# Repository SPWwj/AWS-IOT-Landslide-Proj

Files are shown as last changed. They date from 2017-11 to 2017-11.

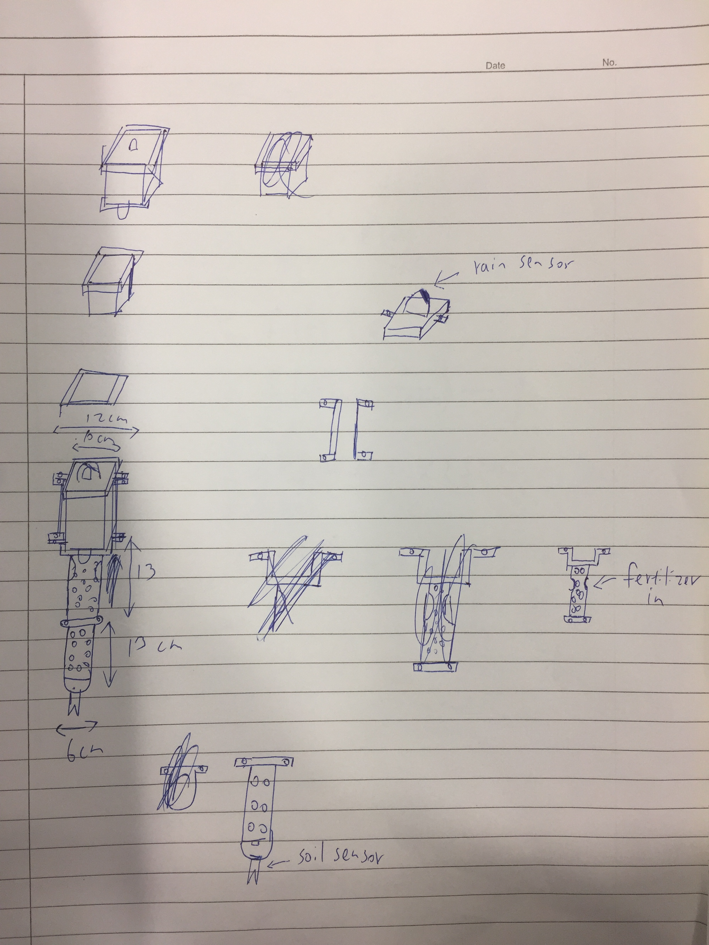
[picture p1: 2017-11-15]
3DDesign/3dSketch.JPG

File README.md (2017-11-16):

**1. Introduction**

SPMakers is a team of two year two students taking Diploma in Computer Engineering in Singapore Polytechnic. We are inspired to build an end-to-end IoT cloud computing system to make the world a better and safer place to live. The MakeSense1 is our solution, utilizing our self-developed IoT enabled microcontroller known as the &quot;SPEEEduino&quot; and Amazon Web Service&#39;s various cloud computing services to collect, store and perform computations on data, and finally provides visualization over the Internet using the D3 library.

**2. Problems and Research**

Landslides form silently, with minimal signs, and is considered one of the most difficult natural disasters to predict. Landslides are highly localized, and warnings often come too late for the people living there to take any life-saving action.

**3. Our Solution**

The MakeSense1 aims to acquire environmental parameters relevant to landslides while doubling as a conservation tool, as its hollow tubes with Voronoi patterns allows for one to deposit fertilizer in the tubes, feeding nearby vegetation which proactively prevents landslides. The MakeSense1 also aims to feeds data into a third-party machine learning based landslide prediction platform.

**3.1 System Diagram and Operation**


The MakeSense1 mainly consists of 3 subsystems: (i) Sensing Subsystem; (ii) Cloud Computing Subsystem; and (iii) Visualization Subsystem. The Sensing Subsystem uses the SPEEEduino, an IoT enabled microcontroller, and interfaces with 3 sensors: an IMU (Inertial Measurement Unit), a rainfall sensor, and a soil moisture sensor, contained in a 3D-printed enclosure with an IP65 waterproof box. The SPEEEduino has an ESP8266-01 Wi-Fi module onboard, allowing it to communicate to the Internet via gateways. It is modular and adaptable to technologies like SigFox and LoRa. The Cloud Computing Subsystem uses Amazon&#39;s AWS IoT, SNS and DynamoDB services to capture, store and process data sensed. The Visualization subsystem is a web interface that displays all the data from the database using the D3 library.

MakeSense1 Node


**3.3 Future plans**

Future development plans include (i) mesh networking between individual MakeSense1 nodes, allowing coverage of the entire area with wireless networking and (ii) feeding sensor data into a machine learning platform for early detection of environmental disasters.

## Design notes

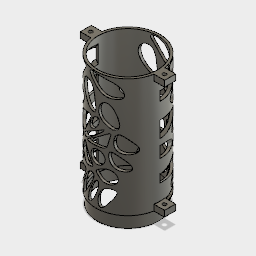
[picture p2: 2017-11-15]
3DDesign/BTMMID/MIDDLEv2 v0XXX.png

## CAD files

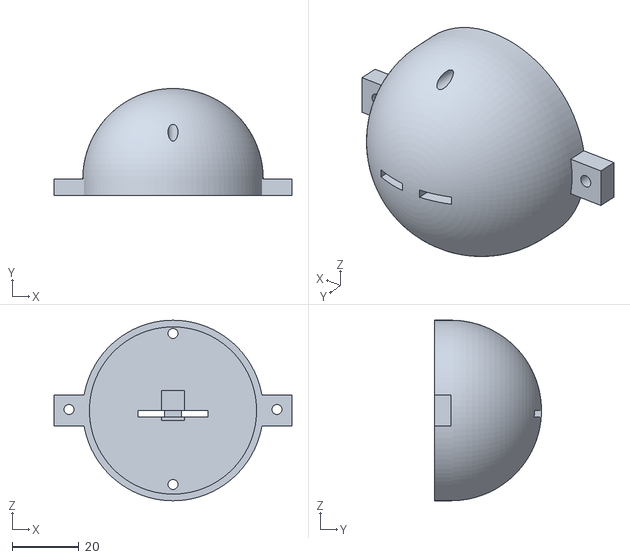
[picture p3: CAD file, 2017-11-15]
3DDesign/BTMBTM/Body5.stl
71.2 x 32.0 x 54.0

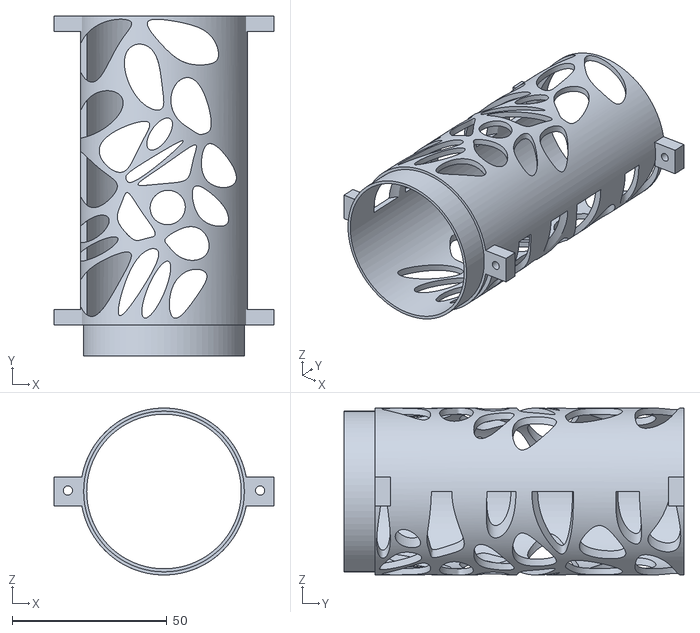
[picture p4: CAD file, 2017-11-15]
3DDesign/BTMMID/Body2.stl
71.2 x 110.0 x 54.0

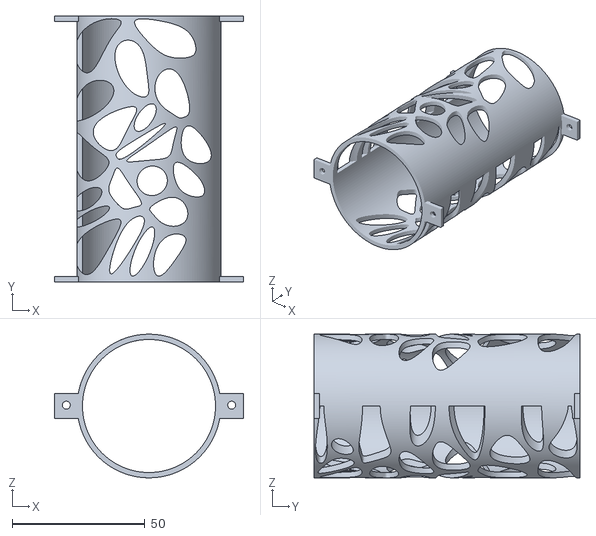
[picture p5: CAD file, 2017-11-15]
3DDesign/BTMMIDRe/Body2.stl
71.2 x 100.0 x 54.0

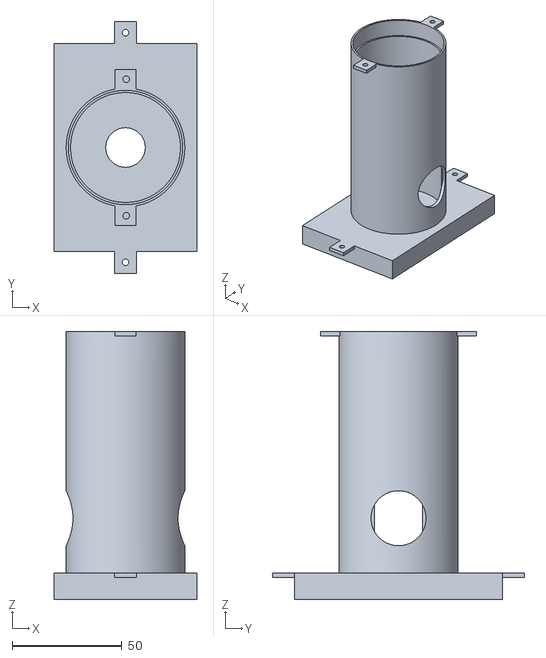
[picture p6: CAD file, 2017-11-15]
3DDesign/BTMTOP/BTMTOPHolderREDOSLT.stl
65.0 x 114.5 x 122.0

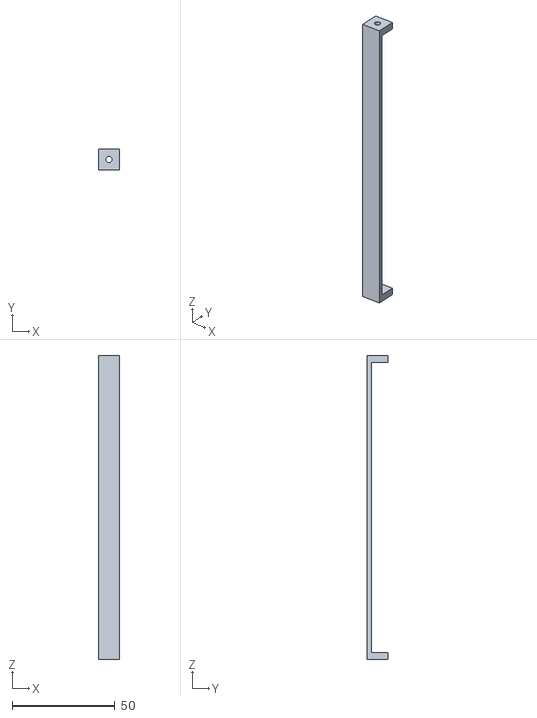
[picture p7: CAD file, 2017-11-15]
3DDesign/Connector/connector148.stl
10.0 x 10.0 x 148.0

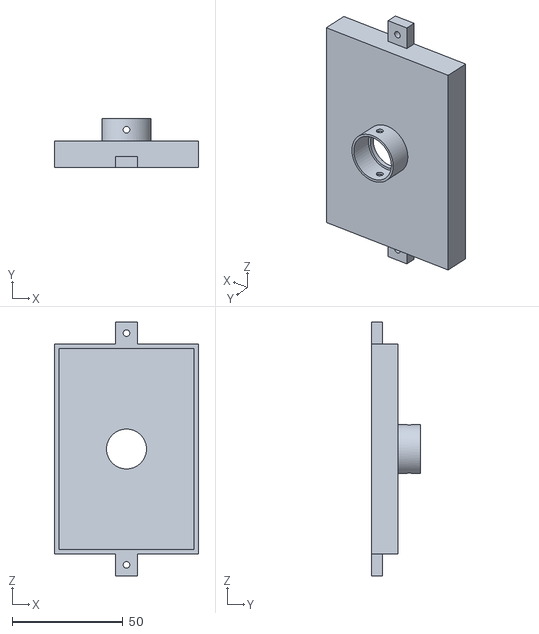
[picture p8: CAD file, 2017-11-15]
3DDesign/TOP/TOPBody1.stl
65.0 x 22.0 x 114.5

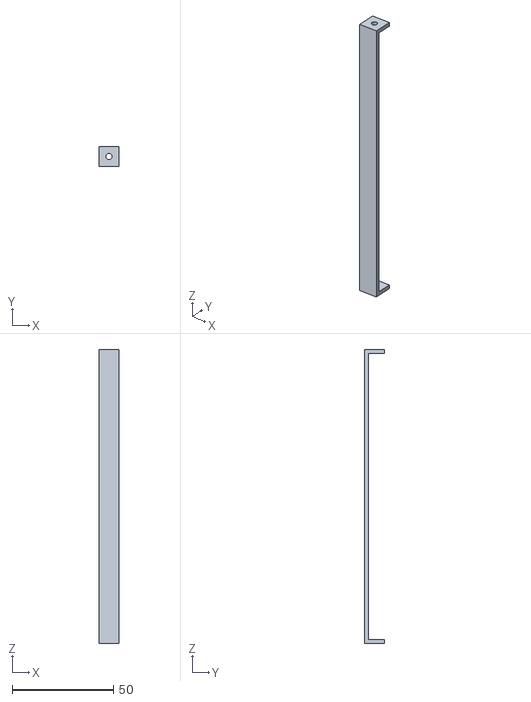
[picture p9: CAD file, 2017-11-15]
3DDesign/Connector/TOPBody1.stl
10.0 x 10.0 x 145.0

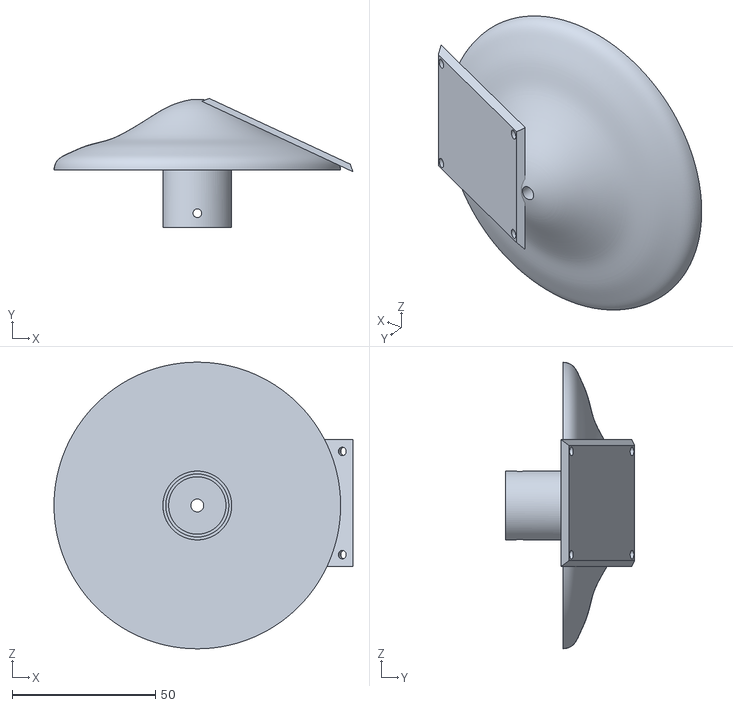
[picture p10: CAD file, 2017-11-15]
3DDesign/TOP/MS.stl
104.3 x 45.1 x 100.0

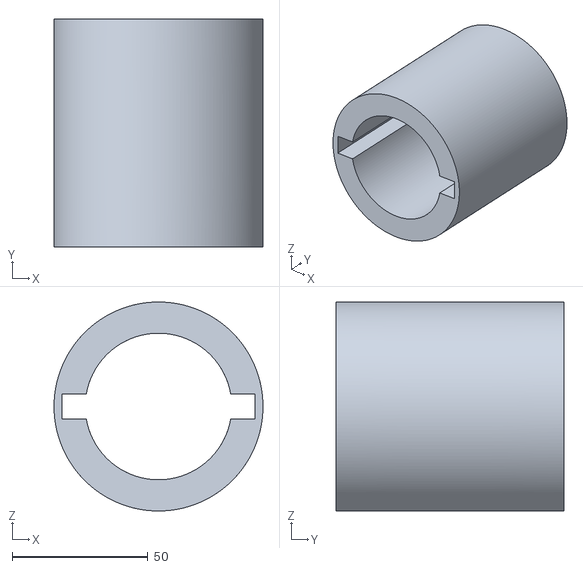
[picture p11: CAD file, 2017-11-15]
3DDesign/Connector/Body15SUPPORT.stl
77.0 x 84.0 x 77.0

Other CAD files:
3DDesign/BTMBTM/btmbtm - Copy.f3d
3DDesign/BTMBTM/btmbtm.f3d
3DDesign/BTMMID/MIDDLEv2 v0XXX.f3d
3DDesign/Connector/Untitled v1.f3d
3DDesign/TOP/modiTOP v4.f3d

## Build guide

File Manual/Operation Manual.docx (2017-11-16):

AWS IoT App Challenge Operation Manual

Title: MakeSense1

Country: Singapore

University/Institute:

Singapore Polytechnic

Members: Pan Ziyue

Wei Wen Jie

Mentor: Teo Shin Jen

# Foreword and Overview

MakeSense1 is significantly different from traditional applications or devices as it is a complete system, spanning from individual hardware nodes to Amazon’s Web Services (AWS) cloud computing platform for data gathering, computation and display. This project utilizes a large variety of code libraries and requires installation prior to compilation. Due to the complexity of this project, a download link is provided below for you to download all of the source code, code libraries, as well as STL object files for 3D printing of the enclosure.

Download link: https://github.com/SPWwj/AWS-IOT-Landslide-Proj

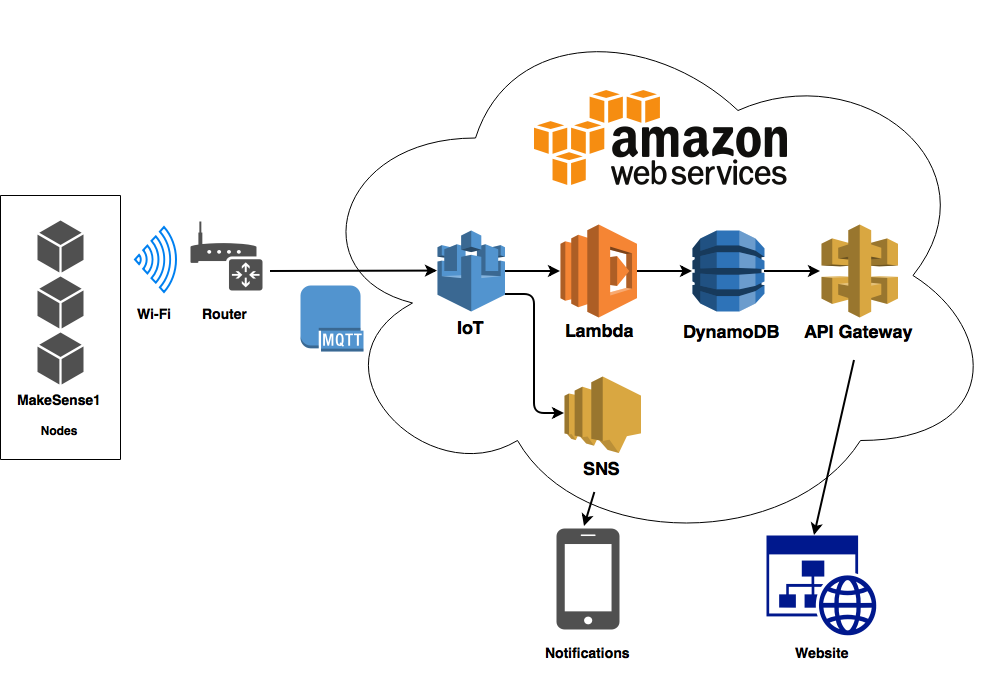
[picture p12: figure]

The MakeSense1 includes 3 subsystems: Sensing, Cloud Computing and Visualization.

The Sensing Subsystem uses the SPEEEduino, a custom designed microcontroller board, and interfaces with 3 sensors, namely: rain, IMU and soil moisture sensors, to sense environmental parameters, and transmits acquired data to AWS IoT over the MQTT protocol.

The user plants MakeSense1 nodes at the location to be monitored. Once turned on, the nodes will connect to a communication network as configured. In our case, we are using Wi-Fi, but it can also be changed to SigFox or LoRa as our design is modular and reprogrammable.

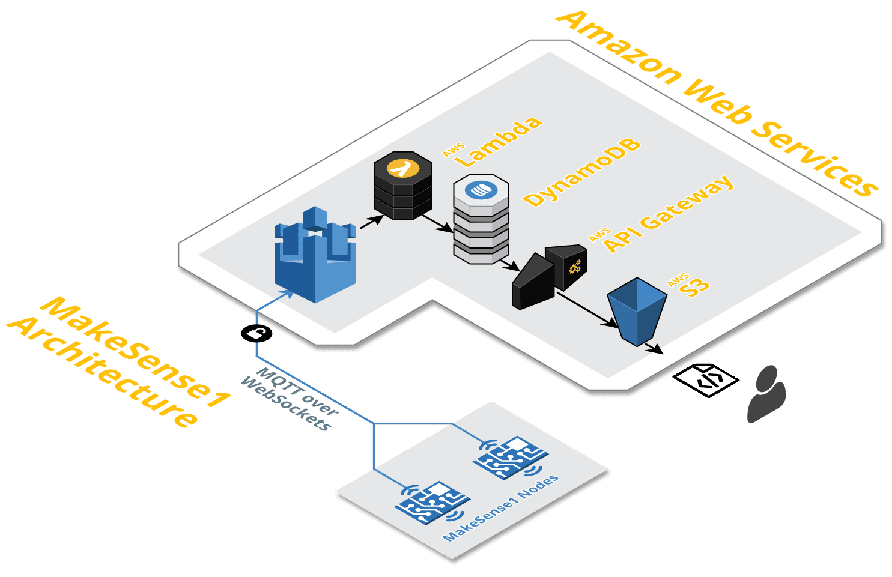
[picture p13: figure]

The Cloud Computing Subsystem uses Amazon’s Web Services’ various services, such as AWS IoT for data capture, DynamoDB for data storage and Lambda for data processing. AWS IoT receives data from the MakeSense1 nodes that triggers a Lambda function which writes the data into DynamoDB for storage and computes a new risk factor for that particular node.

Risk factor computation is one of the key objectives of this project. The risk factor R is computed with roll and pitch of the entire node as well as rainfall and soil moisture.

R=((roll+pitch)/4500+(||rain-1023||+||soil-1023||)/(1446*50))/100

Disclaimer: We open sourced MakeSense1 to enable environmental scientists, researchers and users to evaluate their algorithms and findings on our device. The risk factor computation algorithm shown above is not a scientifically validated algorithm, and requires formal scientific inquiry to improve the accuracy of the algorithm.

The Visualization Subsystem is written in pure HTML/CSS/JavaScript, and can be hosted on any static webpage host, such as Amazon S3, and relies on Google Maps for providing mapping data and D3.js for rendering individual nodes on the map. It accesses the data from DynamoDB using Amazon’s API Gateway.

# Setting Up

This section explains how to setup a complete MakeSense1 system. If you’re not intending to build the hardware system, skip to the Amazon Web Services section.

## SPEEEduino (if you do not own a SPEEEduino you can use an Arduino Uno)

You will need an IP65 waterproof enclosure, a SPEEEduino unit, an ESP-01 ESP8266 Wi-Fi module, a GY-85 IMU module, a soil moisture sensor, and a rain sensor for this part. You may also need connecting wires and a mini-breadboard.

Install the necessary Arduino libraries provided in Arduino Source Code folder in the zip file. Upload ESP8266_Side.ino to the ESP8266 Wi-Fi module and Arduino_Side.ino to the SPEEEduino using the Arduino IDE, making sure to enter your Wi-Fi router name and password, your AWS IoT credentials and the desired device ID into the source code (refer to page 5 and 11 of the Source Code List). Connect the ESP8266 Wi-Fi module to the SPEEEduino’s ESP-01 socket.

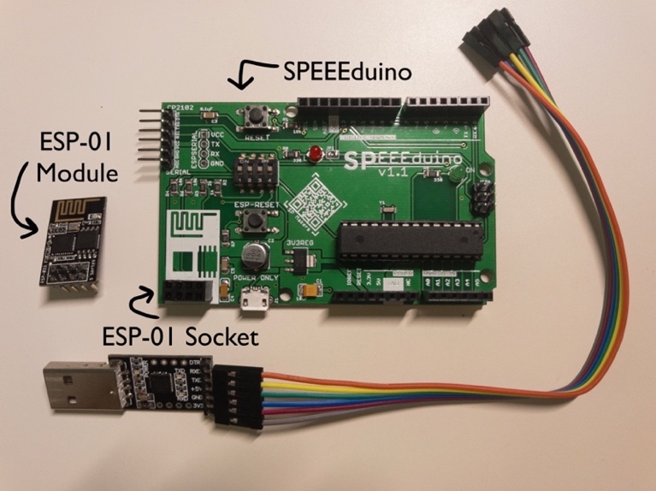
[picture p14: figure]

Connect the GY-85 IMU, soil moisture sensor, and rain sensor to the SPEEEduino according to the pin mapping in Arduino_Side.ino file. You may need jumper wires and a mini-breadboard to connect these components together.

Mount the SPEEEduino, GY-85 and a portable power bank into the IP65 waterproof enclosure. 3D prints the enclosure from the STL files provided in the ‘3D Printing’ folder of the zip file and assemble the components as shown in the diagram below.

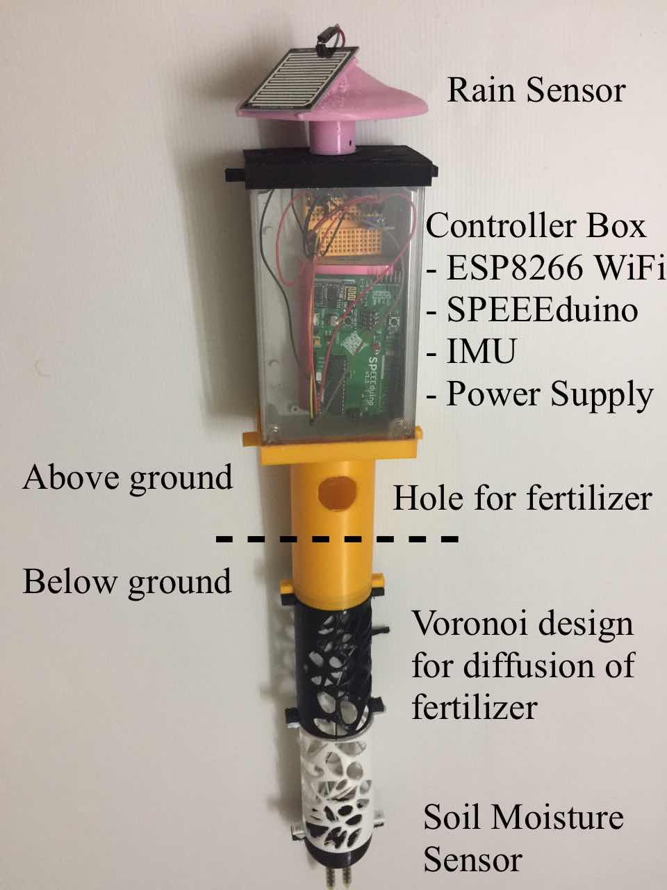
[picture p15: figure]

## Amazon Web Services

You will need an Amazon Web Services account to setup this part. You will need to set up AWS IoT, create a Thing called ‘MakeSense1’ and note down the details, namely the REST API endpoint URL, MQTT update topic, IAM key, IAM secret, AWS region and the MQTT topic.

Create 2 DynamoDB tables, one called ‘devices’ and the other called ‘entries’, with the primary key of each table being ‘deviceID’ and ‘entryUUID’ respectively.

The ‘devices’ table contains data about the individual nodes. You have to fill in the devices table manually before deploying for the system to work. The table below is a sample of what the ‘devices’ table should look like when it is populated with data. deviceID is the primary key and each node has a unique ID assigned to it. lastUpdated contains the last updated UNIX timestamp of the node. lat and long indicate the latitude and longitude of the node. riskFactor is the risk of landslide according to sensor data, computed by a AWS Lambda script.

deviceID | lastUpdated | lat | long | riskFactor
1 | 1505404224 | 1.353197 | 103.777876 | 0.3
0 | 1506002919 | 1.350065 | 103.778273 | 0.019

The ‘entries’ table contains data of every single sensor node at any given instance. A simplified version of the ‘entries’ table is shown below, the actual table has more raw sensor data. entryUUID is a uniquely identifying randomly generated UUID for every single entry, and is the primary key of the table. deviceID is the ID of the device for a given data point.

entryUUID | deviceID | roll | pitch | rain | soil
ff2115f8-2644 | 0 | 140 | 320 | 333 | 325
b9112e89-0712 | 1 | 140 | 319 | 343 | 233

After setting up DynamoDB, you will need to create a new IAM role and assign it to have AmazonDynamoDBFullAccess (https://console.aws.amazon.com/iam/home?region=ap-northeast-1) and CloudWatchLogsFullAccess (https://console.aws.amazon.com/iam/home?region=ap-northeast-1) permissions so as to allow it to access DynamoDB and API Gateway. The Trust Relationship policy also needs to be updated to the one shown in the Source Code List, Cloud Computing Subsystem section.

Copy down the Role ARN as shown below for setting up the API Gateway later on.

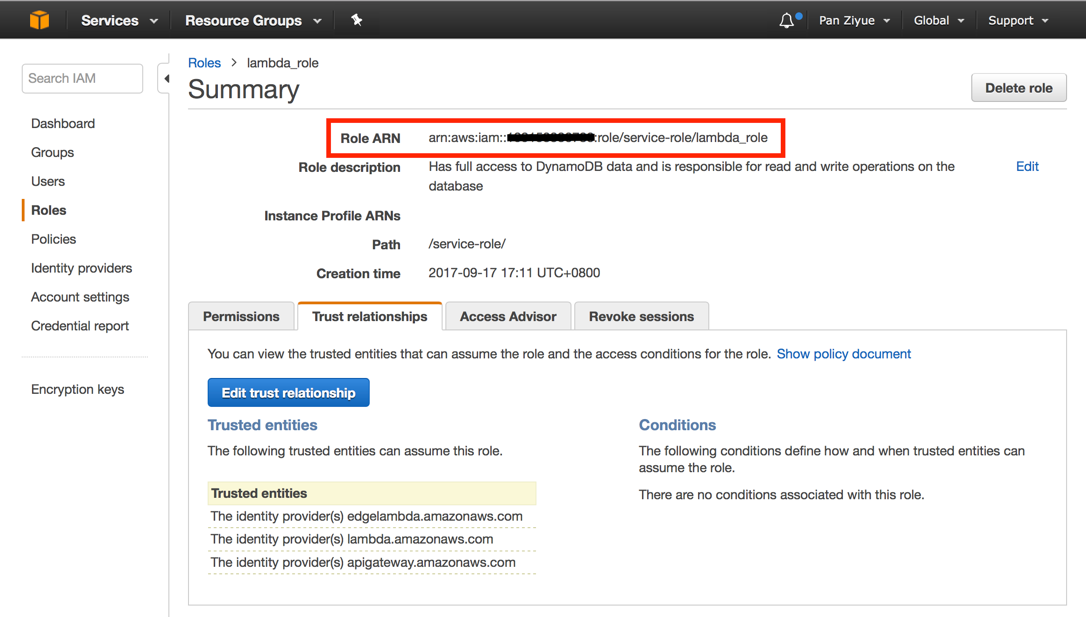
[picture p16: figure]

You can now set up AWS Lambda which bridges AWS IoT and DynamoDB. Create a function from scratch using the AWS Lambda console and add AWS IoT as the trigger, creating a new rule for AWS IoT with the Rule Query Statement which forwards all data from every update request to the Lambda function and make sure that Enable Trigger is checked.

SELECT * FROM '$aws/things/MakeSense1/shadow/update'

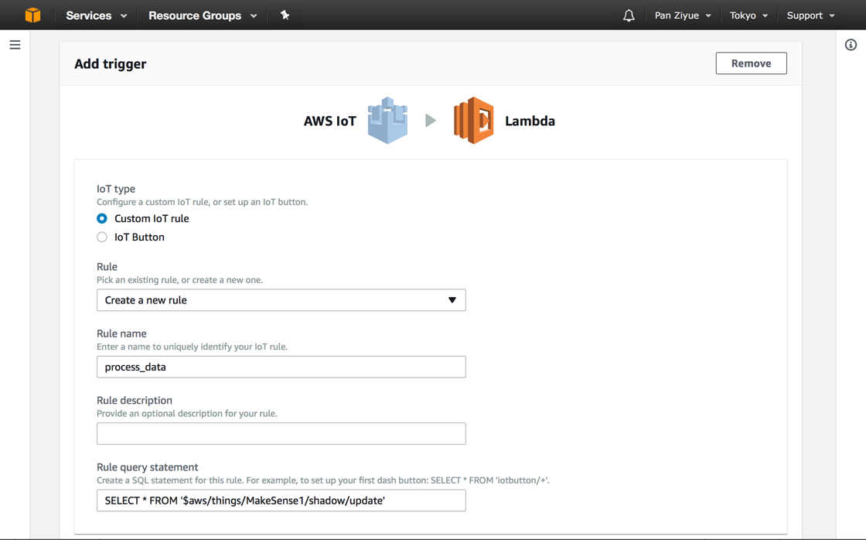
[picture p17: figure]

Now, configure the function runtime to be Python 3.6, and copy-paste write_timestamp_calculate_risk.py into the Lambda function code area.

Select the IAM role you previously created in the Existing role field to grant the Lambda function sufficient permissions to access the database.

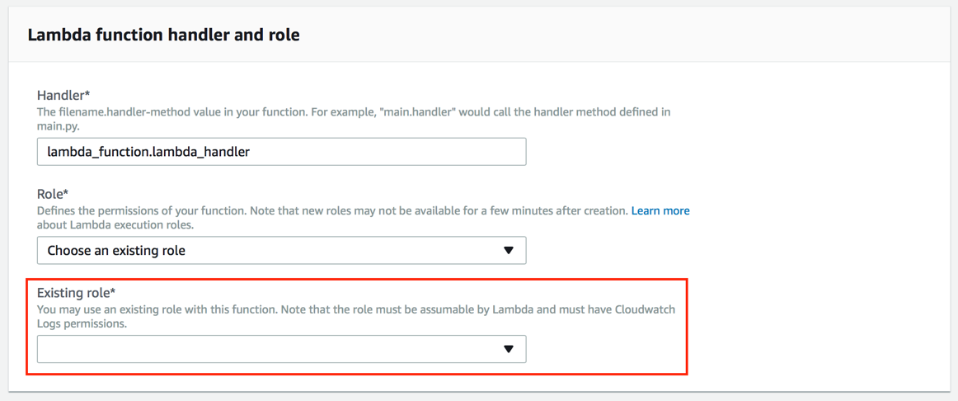
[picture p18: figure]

For the last step, create an API using AWS API Gateway by creating a GET method on the ‘/’ resource, and filling in the form according to the picture below, inserting your Execution Role (ARN) from the step on page 6.

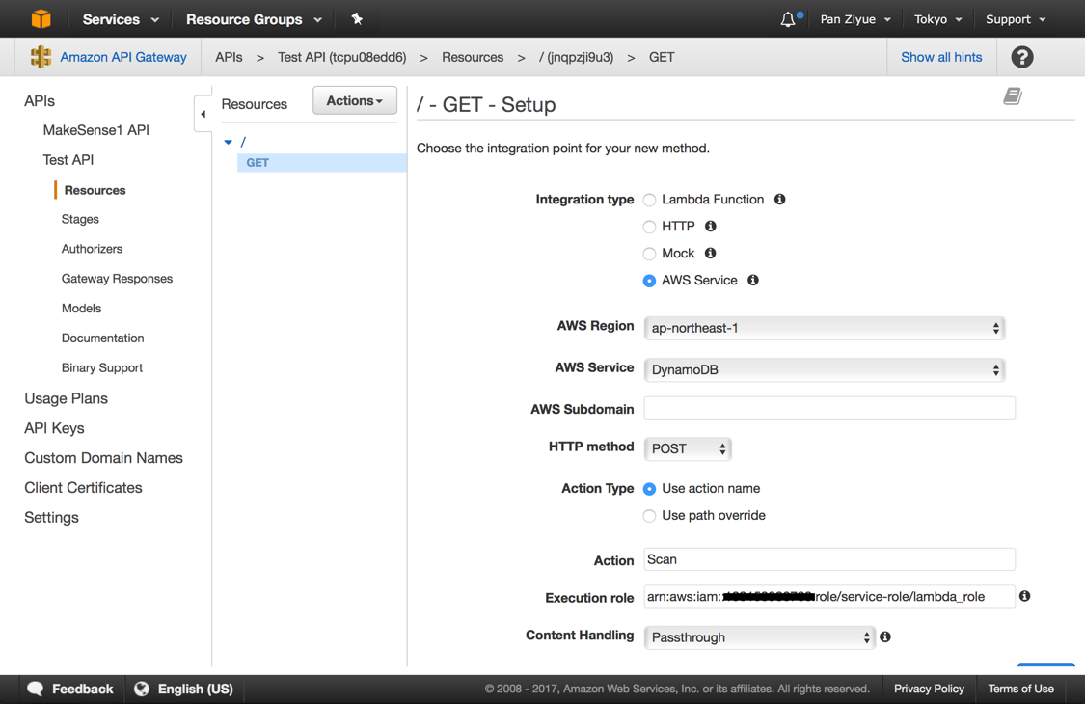
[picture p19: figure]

Configure the Body Mapping Template of the (1) Integration Request and (2) Integration Response using the code provide in "AWS Code” folder. Make sure to configure the Resource to (3) enable CORS (Cross Origin Resource Sharing) so that your browser can download data from the API. Finally, deploy the API.

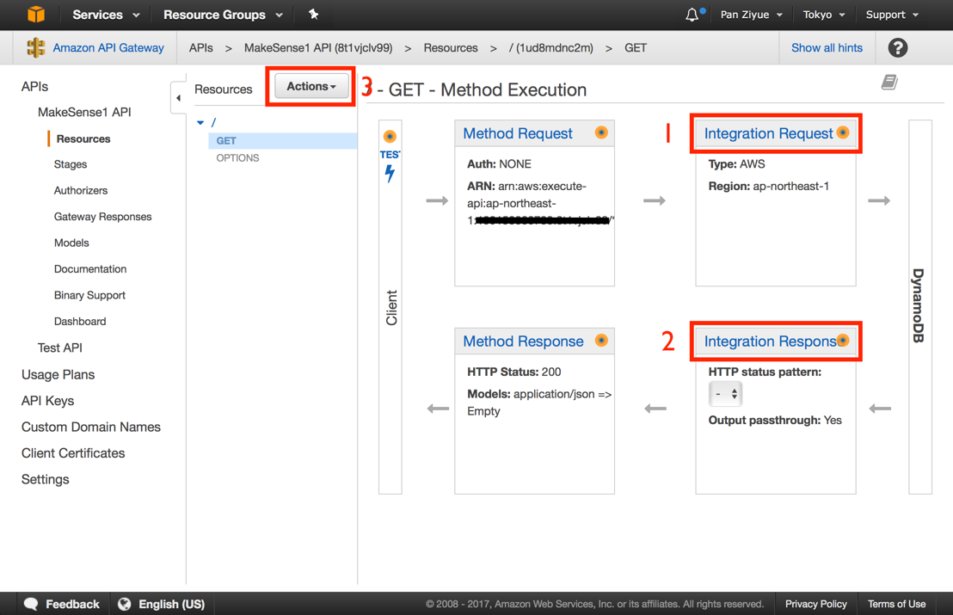
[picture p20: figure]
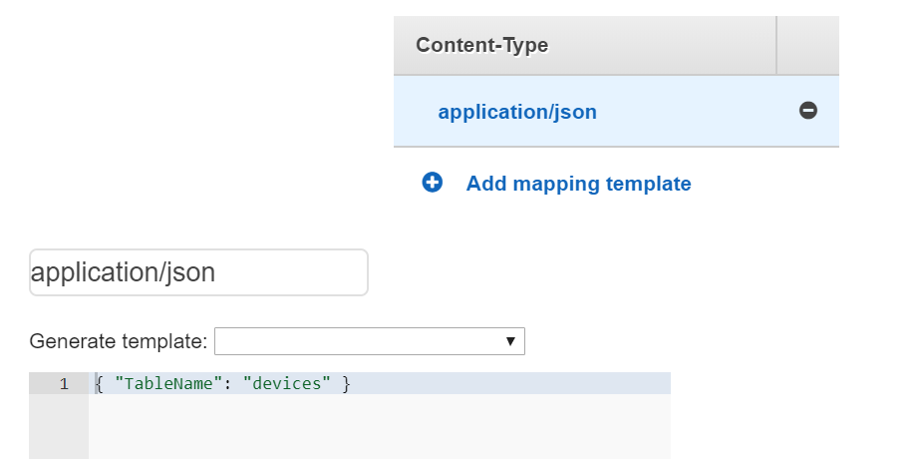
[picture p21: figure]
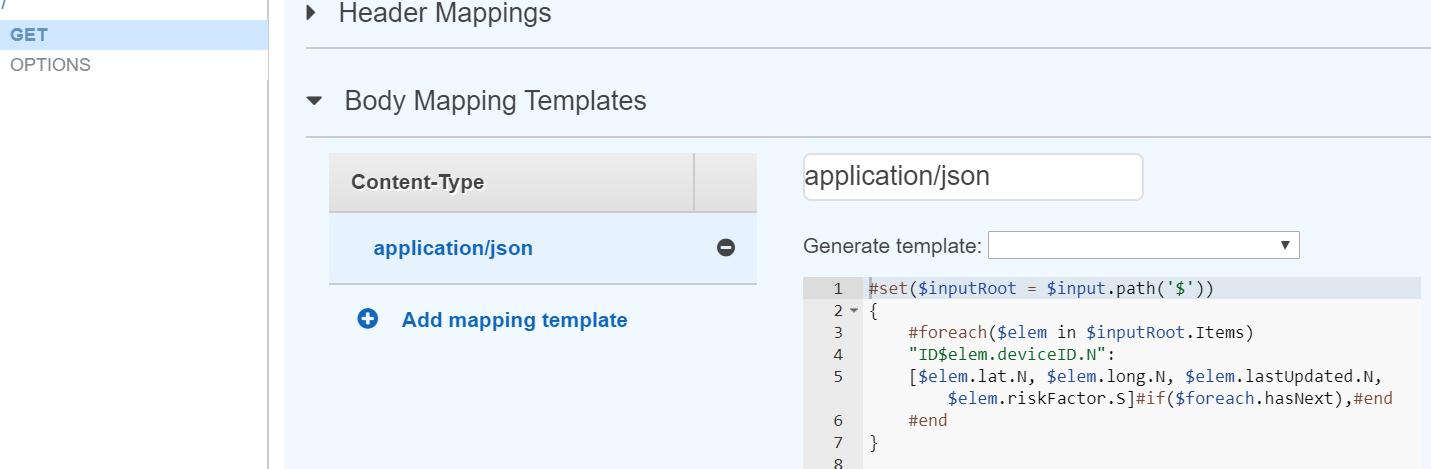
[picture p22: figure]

Next go to Simple Notification Service to set up SMS notification

Select Topics and create a new topic called “dynamodb”

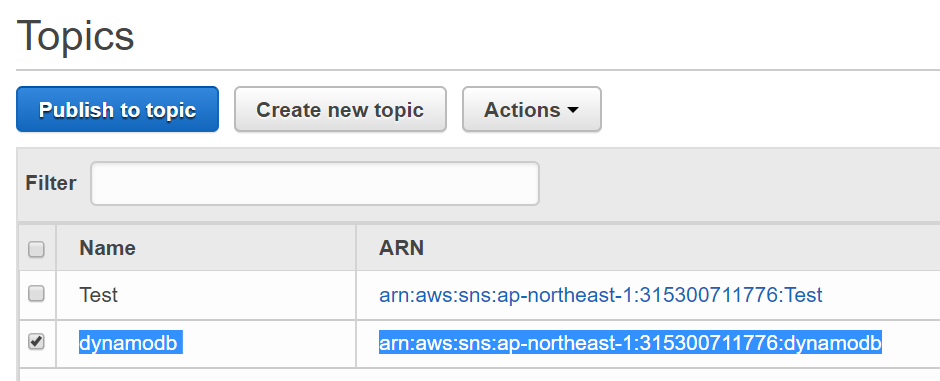
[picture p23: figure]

Then tick the checkbox of your topic, under the Actions click Subscribe to Topic, choose SMS and enter your phone number.

## Visualization Subsystem

The Visualization subsystem is fairly straightforward to set up, and you don’t even have to deploy it onto a server for it to work. Simply tweak the line containing the API URL (looks like var url = "https://8t1vjclv99.execute-api.ap-northeast-1.amazonaws.com/Production";) to your API’s actual URL and double click index.html in the ‘D3 Visualization’ folder of the source code zip file. It should present you with the MakeSense1 Console, which shows all of the nodes and their respective risk factors. In our demonstration unit, we preprogrammed the coordinates of the nodes to be around Bukit Timah Hill, which is the only place in Singapore with significant elevations above sea level. If you wish to deploy it onto a server, Amazon’s S3 static hosting service can be used. Now you can power on your device to see data streaming in and protect your property from landslides.

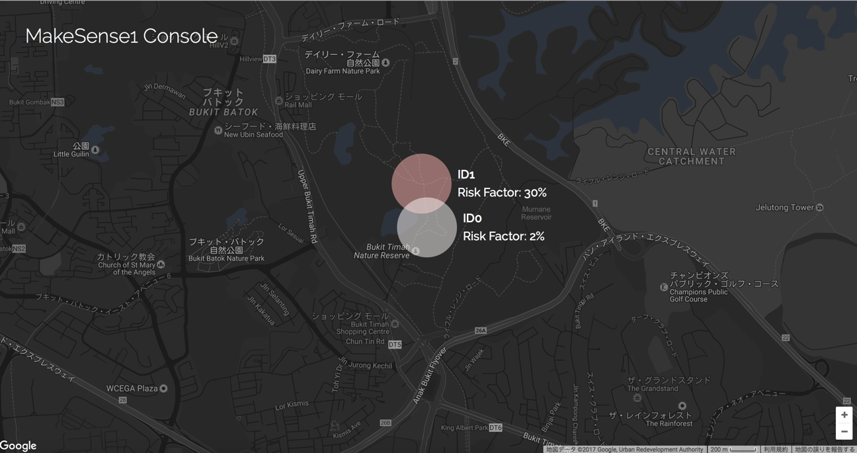
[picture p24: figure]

# Demo Instructions (Without actual hardware)

If you want to test out the Cloud and Visualization systems without building the actual hardware, follow the instructions below:

1) Fire up the Visualization subsystem by opening the index.html file in the D3 folder under our GitHub repository.
2) Open the AWS IoT MQTT client (you must set up your own AWS IoT account, if you are using our AWS Setup, please use our private key in the Zip file).
3) Copy the sample sensor data in D3 folder under GitHub repository to the input field of the MQTT client (and tweak the values to vary the risk factor output).
4) Publish the sensor data to your AWS IoT topic (in our case, it is $aws/things/MakeSense1/shadow/update)
5) Enjoy using the MakeSense1!

// Sample Sensor Data:

{

"state": {

"reported": {}

},

"entryUUID": "e55bc185-015b-4864-aea4-648f9f05f0de",

"deviceID": 0,

"status": 0,

"soil": 300,

"rain": 300,

"accl_x": 0,

"accl_y": 0,

"accl_z": 0,

"gyro_x": -0.56,

"gyro_y": -0.28,

"gyro_z": 0.42

}

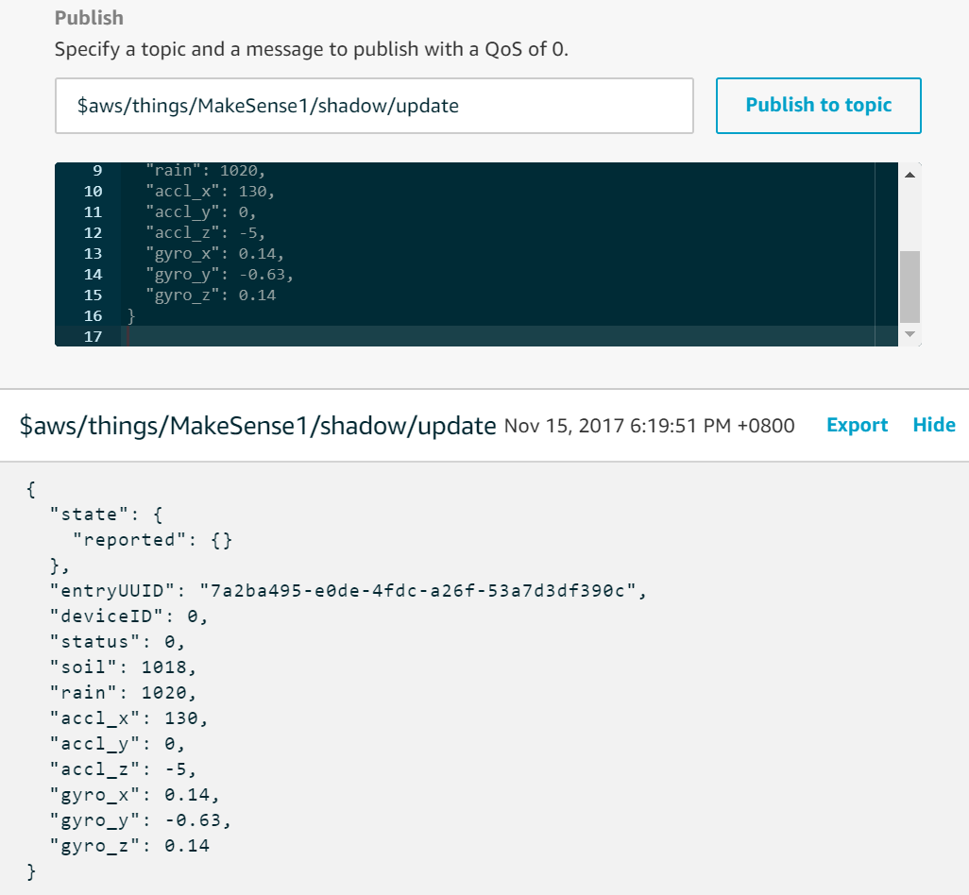
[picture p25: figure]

# Setting up MQTT client using mqtt.fx

1)

Enter the Broker Address as AWS IOT End point

Broker port 8883

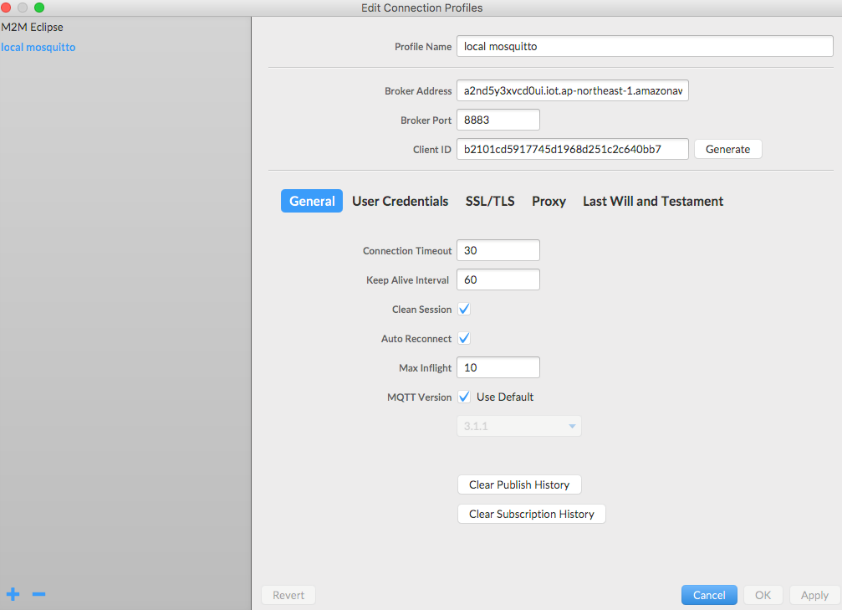
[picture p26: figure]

2)

Go to SSL/TLS tab

Select the Self signed certificates and enter the certs respectively

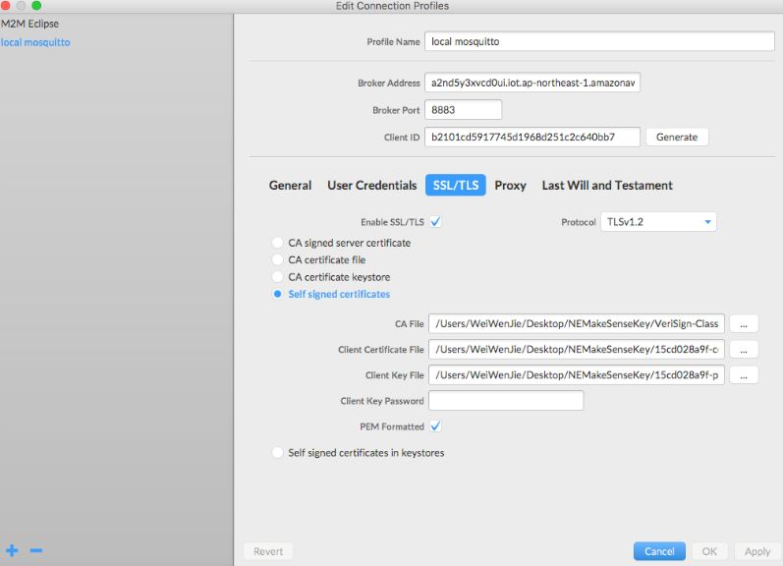
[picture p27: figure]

3)

Lastly Publish the sensor data to the Topic “$aws/things/MakeSense1/shadow/update”

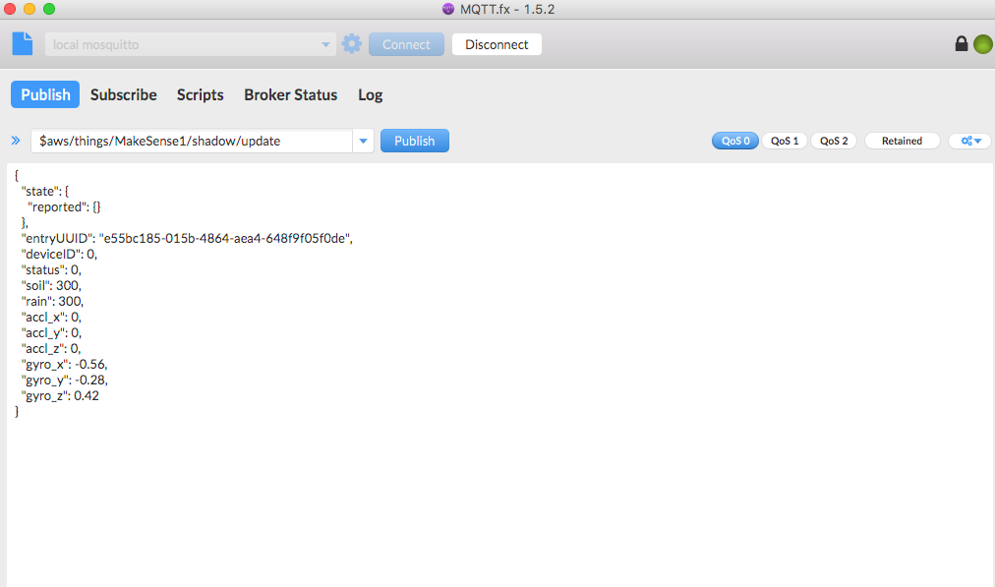
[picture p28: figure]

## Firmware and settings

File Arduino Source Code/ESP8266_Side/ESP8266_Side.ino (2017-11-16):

/**************** Library include directives ****************/

#include <Arduino.h>
#include <Stream.h>
#include <ESP8266WiFi.h>
#include <ESP8266WiFiMulti.h>
#include <ESP8266TrueRandom.h>

//AWS
#include "sha256.h"
#include "Utils.h"
#include "AWSClient2.h"

//WEBSockets
#include <Hash.h>
#include <WebSocketsClient.h>

//MQTT PAHO
#include <SPI.h>
#include <IPStack.h>
#include <Countdown.h>
#include <MQTTClient.h>

//AWS MQTT Websocket
#include "Client.h"
#include "AWSWebSocketClient.h"
#include "CircularByteBuffer.h"

/**************** Constants declarations ****************/
// Please change the parameters below to match your local configuration
// The variables below are for reference only
char wifi_ssid[]       = "Your Wifi SSID";
char wifi_password[]   = "Your Wifi Password";
char aws_endpoint[]    = "AWS ENDPOINT";
char aws_key[]         = "AWS KEY";
char aws_secret[]      = "AWS SECRET";
char aws_region[]      = "REGION";
const char* aws_topic  = "Your Topic"//"$aws/things/MakeSense1/shadow/update";
int port = 443;

#define DEBUG_PRINT 0

const int maxMQTTpackageSize = 512;
const int maxMQTTMessageHandlers = 1;

/**************** Variable declarations ****************/
ESP8266WiFiMulti WiFiMulti;

AWSWebSocketClient awsWSclient(1000);

IPStack ipstack(awsWSclient);
MQTT::Client<IPStack, Countdown, maxMQTTpackageSize, maxMQTTMessageHandlers> *client = NULL;

long connection = 0;

/**************** Helper function declarations ****************/

//generate random mqtt clientID
char* generateClientID() {
  char* cID = new char[23]();
  for (int i=0; i<22; i+=1)
  cID[i]=(char)random(1, 256);
  return cID;
}

//count messages arrived
int arrivedcount = 0;

//callback to handle mqtt messages
void messageArrived(MQTT::MessageData& md) {
  MQTT::Message &message = md.message;

  if (DEBUG_PRINT) {
    Serial.print("Message ");
    Serial.print(++arrivedcount);
    Serial.print(" arrived: qos ");
    Serial.print(message.qos);
    Serial.print(", retained ");
    Serial.print(message.retained);
    Serial.print(", dup ");
    Serial.print(message.dup);
    Serial.print(", packetid ");
    Serial.println(message.id);
    Serial.print("Payload ");
    char* msg = new char[message.payloadlen+1]();
    memcpy (msg,message.payload,message.payloadlen);
    Serial.println(msg);
    delete msg;
  }
}

//connects to websocket layer and mqtt layer
bool connect() {
  if (client == NULL) {
    client = new MQTT::Client<IPStack, Countdown, maxMQTTpackageSize, maxMQTTMessageHandlers>(ipstack);
  } else {

    if (client->isConnected()) {
      client->disconnect();
    }
    delete client;
    client = new MQTT::Client<IPStack, Countdown, maxMQTTpackageSize, maxMQTTMessageHandlers>(ipstack);
  }

  //delay is not necessary... it just help us to get a "trustful" heap space value
  delay (1000);
  if (DEBUG_PRINT) {
    Serial.print (millis());
    Serial.print (" - conn: ");
    Serial.print (++connection);
    Serial.print (" - (");
    Serial.print (ESP.getFreeHeap ());
    Serial.println (")");
  }

  int rc = ipstack.connect(aws_endpoint, port);
  if (rc != 1)
  {
    if (DEBUG_PRINT) {
      Serial.println("error connection to the websocket server");
    }
    return false;
  } else {
    if (DEBUG_PRINT) {
      Serial.println("websocket layer connected");
    }
  }

  if (DEBUG_PRINT) {
    Serial.println("MQTT connecting");
  }

  MQTTPacket_connectData data = MQTTPacket_connectData_initializer;
  data.MQTTVersion = 3;
  char* clientID = generateClientID();
  data.clientID.cstring = clientID;
  rc = client->connect(data);
  delete[] clientID;
  if (rc != 0)
  {
    if (DEBUG_PRINT) {
      Serial.print("error connection to MQTT server");
      Serial.println(rc);
      return false;
    }
  }
  if (DEBUG_PRINT) {
    Serial.println("MQTT connected");
  }
  return true;
}

//subscribe to a mqtt topic
void subscribe() {
  //subscribe to a topic
  int rc = client->subscribe(aws_topic, MQTT::QOS0, messageArrived);
  if (rc != 0) {
    if (DEBUG_PRINT) {
      Serial.print("rc from MQTT subscribe is ");
      Serial.println(rc);
    }
    return;
  }
  if (DEBUG_PRINT) {
    Serial.println("MQTT subscribed");
  }
}

void waitForWifi() {
  while(WiFiMulti.run() != WL_CONNECTED) {
    delay(100);
    if (DEBUG_PRINT) {
      Serial.println("waiting for wifi");
    }
  }
  if (DEBUG_PRINT) {
    Serial.println("\nconnected to network " + String(wifi_ssid) + "\n");
  }
}

String getValue(String data, char separator, int index) {
    int found = 0;
    int strIndex[] = { 0, -1 };
    int maxIndex = data.length() - 1;

    for (int i = 0; i <= maxIndex && found <= index; i++) {
        if (data.charAt(i) == separator || i == maxIndex) {
            found++;
            strIndex[0] = strIndex[1] + 1;
            strIndex[1] = (i == maxIndex) ? i+1 : i;
        }
    }
    return found > index ? data.substring(strIndex[0], strIndex[1]) : "";
}

/**************** Main Program ****************/

void setup() {
  Serial.begin(9600);
  WiFiMulti.addAP(wifi_ssid, wifi_password);

  waitForWifi();

  awsWSclient.setAWSRegion(aws_region);
  awsWSclient.setAWSDomain(aws_endpoint);
  awsWSclient.setAWSKeyID(aws_key);
  awsWSclient.setAWSSecretKey(aws_secret);
  awsWSclient.setUseSSL(true);
}

void loop() {
  // Perform reading from Arduino side
  // ESP8266 sends a single '.' character (ASCII code 0x2E)
  // Arduino returns CSV style with LF line ending
  // Format: Soil[0,1023],Rain[0,1023],Accl_X[-255,255],Accl_Y[-255,255],Accl_Z[-255,255]
  unsigned long timeout = millis() + 2000UL; // 2 second timeout
  Serial.print(".");
  String inData = "";
  while (1) {
    if (millis() > timeout) {
      break;
    }
    while (Serial.available()) {
      char received = Serial.read();
      if (received == '\n') {
        goto response;
      }
      inData += received;
    }
  }

response:
  bool sensorError = false;
  if (inData.length() < 1) {
    if (DEBUG_PRINT) {
      Serial.println("Error reading device sensor");
    }
    sensorError = true;
  }

  // Split up response
  String soil = getValue(inData, ',', 0);
  String rain = getValue(inData, ',', 1);
  String accl_x = getValue(inData, ',', 2);
  String accl_y = getValue(inData, ',', 3);
  String accl_z = getValue(inData, ',', 4);
  String gyro_x = getValue(inData, ',', 5);
  String gyro_y = getValue(inData, ',', 6);
  String gyro_z = getValue(inData, ',', 7);

  if (sensorError) {
    soil = "null";
    rain = "null";
    accl_x = "null";
    accl_y = "null";
    accl_z = "null";
    gyro_x = "null";
    gyro_y = "null";
    gyro_z = "null";
  }

  // Construct message to send to AWS IoT
  String values = "{\"state\":{\"reported\":{}},\"entryUUID\":\"";
  uint8_t uuid[16];
  ESP8266TrueRandom.uuid(uuid);
  values += ESP8266TrueRandom.uuidToString(uuid);
  values += "\",\"deviceID\":0";
  if (sensorError) {
    values += ",\"status\":-1";
  } else {
    values += ",\"status\":0";
    values += ",\"soil\":"+ soil;
    values += ",\"rain\":"+ rain;
    values += ",\"accl_x\":"+ accl_x;
    values += ",\"accl_y\":"+ accl_y;
    values += ",\"accl_z\":"+ accl_z;
    values += ",\"gyro_x\":"+ gyro_x;
    values += ",\"gyro_y\":"+ gyro_y;
    values += ",\"gyro_z\":"+ gyro_z;
  }
  values += "}";
  const char *publish_message = values.c_str();

  // Connect (if not yet connected) and send message
  if (awsWSclient.connected()) {
    client->yield();
    subscribe();
    //publish
    MQTT::Message message;
    char buf[1000];
    strcpy(buf, publish_message);
    message.qos = MQTT::QOS0;
    message.retained = false;
    message.dup = false;
    message.payload = (void*)buf;
    message.payloadlen = strlen(buf)+1;
    int rc = client->publish(aws_topic, message);
  } else {
    //handle reconnection
    connect();
  }

  // Send next message 5 seconds later
  delay(1000);
}

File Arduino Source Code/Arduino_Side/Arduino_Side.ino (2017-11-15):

/**************** Pin mapping ****************/

/*
 * GY-85 IMU
 * VCC_IN  ->   5V
 * GND     ->   GND
 * SCL     ->   A5
 * SDA     ->   A4
 *
 * Rainfall detector
 * VCC_IN  ->   5V
 * GND     ->   GND
 * A0      ->   A0
 * D0      ->   NC
 *
 * Soil Moisture Sensor
 * VCC_IN  ->   5V
 * GND     ->   GND
 * A0      ->   A1
 * D0      ->   NC (no connect)
 */

/**************** Library include directives ****************/

#include "GY_85.h"
#include <Wire.h>
#include <SoftwareSerial.h>

/**************** Variable declarations ****************/

SoftwareSerial esp8266(2,4);

//GY85 IMU
GY_85 gy85;
int ax, ay ,az;
float gx, gy, gz;

// Rain and soil moisture values
int rainValue, soilMoistureValue;

/**************** Helper functions ****************/

void readSensors() {
  ax = gy85.accelerometer_x(gy85.readFromAccelerometer());
  ay = gy85.accelerometer_y(gy85.readFromAccelerometer());
  az = gy85.accelerometer_z(gy85.readFromAccelerometer());
  gx = gy85.gyro_x(gy85.readGyro());
  gy = gy85.gyro_y(gy85.readGyro());
  gz = gy85.gyro_z(gy85.readGyro());
  rainValue = analogRead(A0);
  soilMoistureValue = analogRead(A1);
}

/**************** Main Program ****************/

void setup() {
  // Setup ESP8266 serial port
  Serial.begin(9600);
  esp8266.begin(9600);

  // Setup GY855 IMU
  Wire.begin();
  delay(10);
  gy85.init();
  delay(10);

  // Setup onboard LED for status indication
  pinMode(LED_BUILTIN, OUTPUT);
}

void loop() {
  // Wait for '.' character
  while (esp8266.available()) {
    if (esp8266.read() == '.') {
      // Read sensors
      readSensors();
      // Construct data and send payload
      esp8266.print(soilMoistureValue);
      esp8266.print(',');
      esp8266.print(rainValue);
      esp8266.print(',');
      esp8266.print(ax);
      esp8266.print(',');
      esp8266.print(ay);
      esp8266.print(',');
      esp8266.print(az);
      esp8266.print(',');
      esp8266.print(gx);
      esp8266.print(',');
      esp8266.print(gy);
      esp8266.print(',');
      esp8266.println(gz);

      // For debug only
      Serial.print(soilMoistureValue);
      Serial.print(',');
      Serial.print(rainValue);
      Serial.print(',');
      Serial.print(ax);
      Serial.print(',');
      Serial.print(ay);
      Serial.print(',');
      Serial.print(az);
      Serial.print(',');
      Serial.print(gx);
      Serial.print(',');
      Serial.print(gy);
      Serial.print(',');
      Serial.println(gz);

      // Blink LED to indicate that ESP8266 has requested data
      digitalWrite(LED_BUILTIN, HIGH);
      delay(0.5);
      digitalWrite(LED_BUILTIN, LOW);
    }
  }
}
